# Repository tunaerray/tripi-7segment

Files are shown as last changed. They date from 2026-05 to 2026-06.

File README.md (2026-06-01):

# TRIPI 7-Segment Display Module

A peripheral expansion board designed for the TRIPI (Trion-based FPGA) platform, featuring 8 seven-segment displays, external push buttons, switches, and a reset mechanism.

## Overview

This project provides a ready-to-use hardware module for FPGA-based digital logic and display control applications. The board connects directly to the 40-pin GPIO header of the TRIPI FPGA board, enabling students and developers to implement and test digital systems without additional wiring or breadboarding.

## Features

- 8x seven-segment displays for multi-digit numeric output
- External push buttons and switches for user input
- Reset functionality for system control
- 2-layer PCB designed for the TRIPI FPGA 40-pin GPIO header
- Plug-and-play integration with the Trion-based FPGA platform

## Use Case

Designed as an educational hardware platform, this module allows students to:

- Implement digital logic circuits on a real FPGA
- Develop display control and multiplexing applications
- Prototype FPGA-based digital systems
- Learn hardware-software co-design in an embedded context

## Hardware

- **Platform:** TRIPI (Trion-based FPGA)
- **Interface:** 40-pin GPIO header
- **PCB:** 2-layer board
- **Display:** 8x seven-segment displays
- **Input:** Push buttons, DIP switches, reset button

## Images

### PCB Front

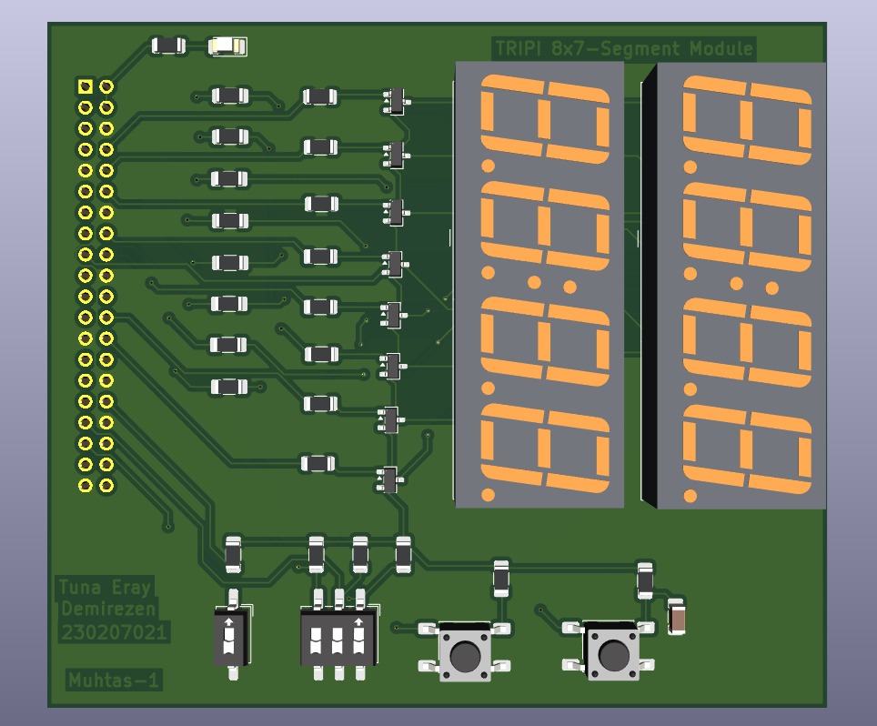
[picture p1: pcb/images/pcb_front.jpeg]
PCB Front


### PCB Back

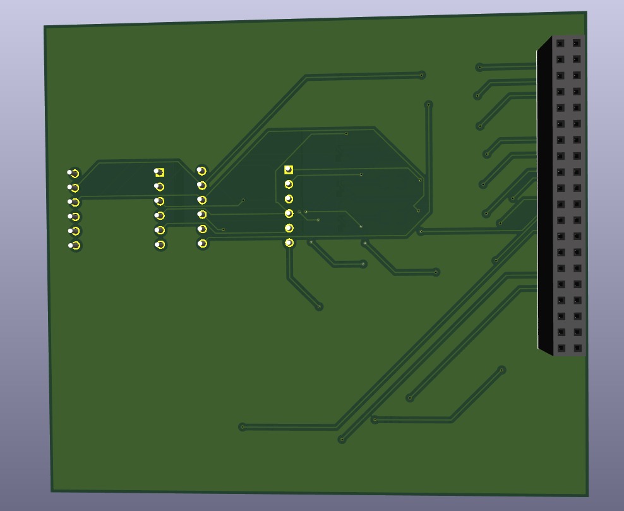
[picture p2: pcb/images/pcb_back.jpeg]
PCB Back

.

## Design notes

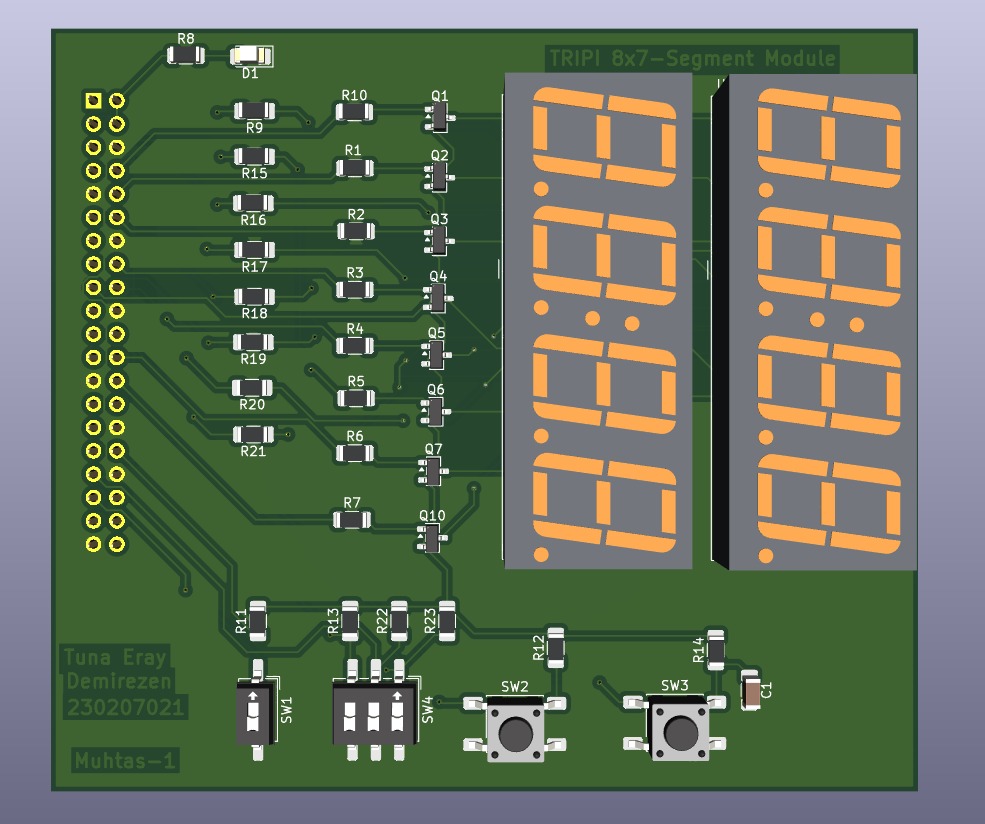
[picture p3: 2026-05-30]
pcb/images/tripi_7segment_pcb_front.jpeg

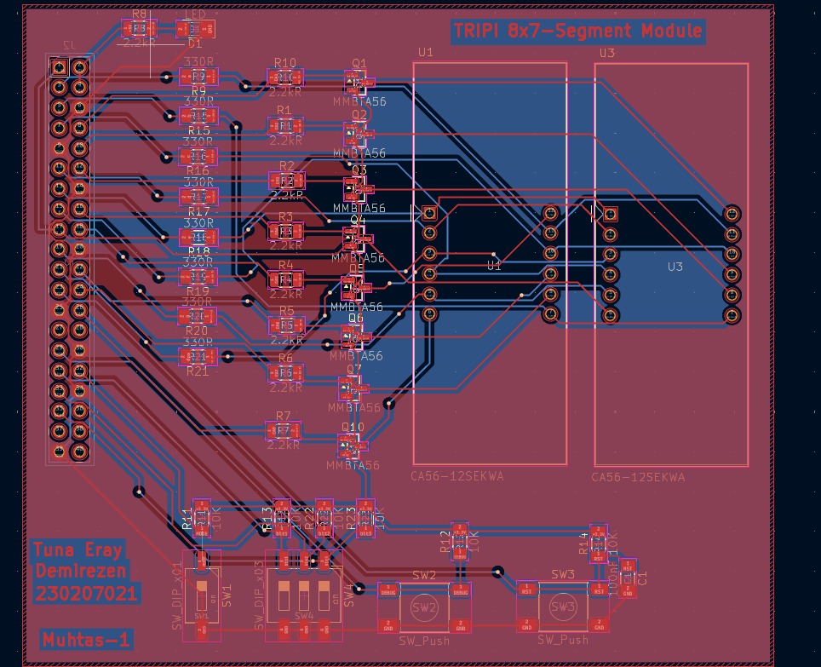
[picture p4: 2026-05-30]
pcb/images/pcb_layout.jpeg

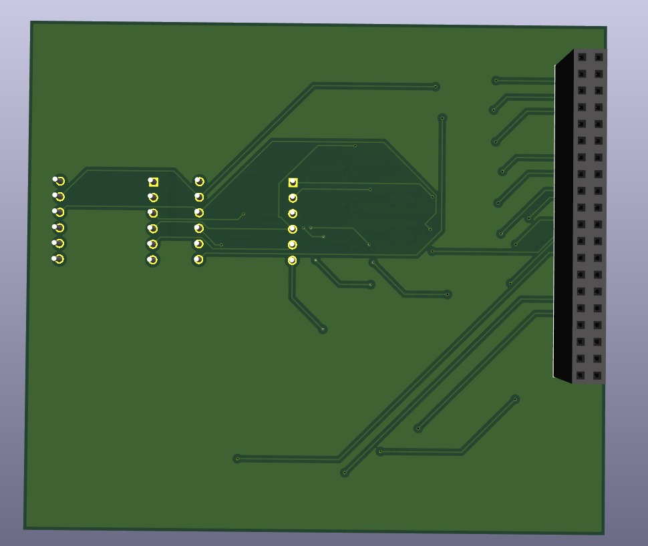
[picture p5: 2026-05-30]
pcb/images/tripi_7segment_pcb_back.jpeg

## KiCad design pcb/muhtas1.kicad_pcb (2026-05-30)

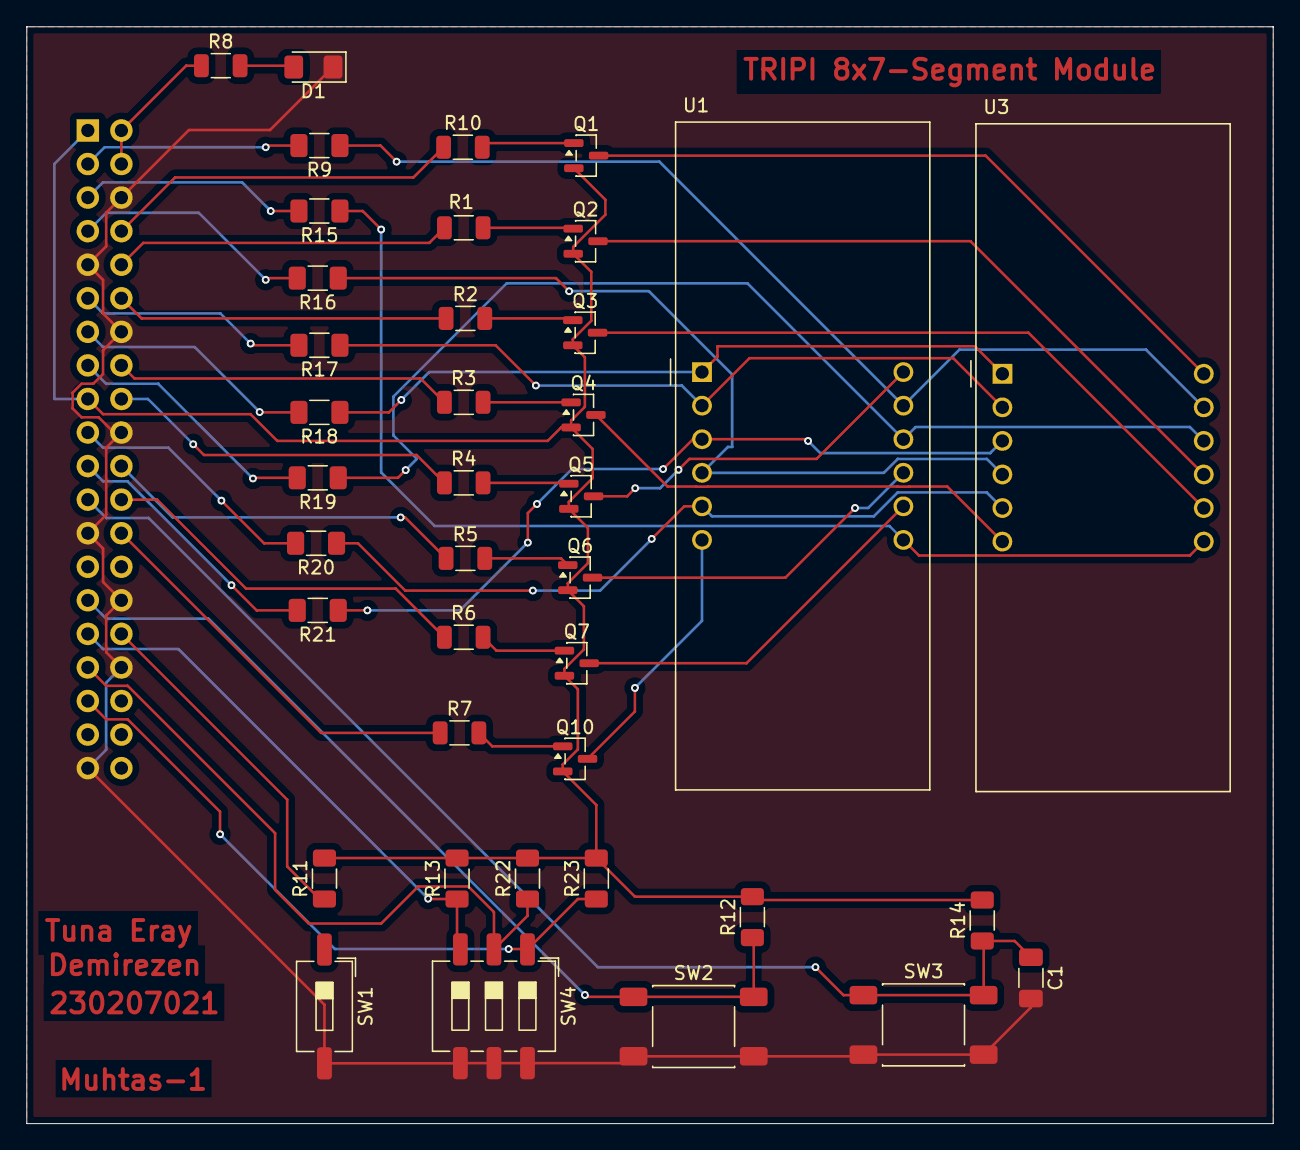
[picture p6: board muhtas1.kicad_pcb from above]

Board: 2 copper layers, 94.3 x 83.0 mm, 40 parts (1 on the bottom side), 50 nets.

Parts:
C1: 100nF; C_1206_3216Metric_Pad1.33x1.80mm_HandSolder
D1: LED; LED_1206_3216Metric_Pad1.42x1.75mm_HandSolder
J2: Conn_02x20_Odd_Even; PinSocket_2x20_P2.54mm_Vertical
Q1, Q2, Q3, Q4, Q5, Q6, Q7, Q10: MMBTA56; SOT-23
R1, R2, R3, R4, R5, R6, R7, R8, R10: 2.2kR; R_1206_3216Metric
R9, R15, R16, R17, R18, R19, R20, R21: 330R; R_1206_3216Metric_Pad1.30x1.75mm_HandSolder
R11, R12, R13, R14, R22, R23: 10K; R_1206_3216Metric_Pad1.30x1.75mm_HandSolder
SW1: SW_DIP_x01; SW_DIP_SPSTx01_Slide_6.7x4.1mm_W8.61mm_P2.54mm_LowProfile
SW2, SW3: SW_Push; SW_Push_1P1T_NO_E-Switch_TL3301NxxxxxG
SW4: SW_DIP_x03; SW_DIP_SPSTx03_Slide_6.7x9.18mm_W8.61mm_P2.54mm_LowProfile
U1, U3: CA56-12SEKWA

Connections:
+3.3V: J2.1, J2.17, Q1.2 (E), Q2.2 (E), Q3.2 (E), Q4.2 (E), Q5.2 (E), Q6.2 (E), Q7.2 (E), Q10.2 (E), R11.2, R12.2, R13.2, R14.2, R22.2, R23.2
+5V: J2.2, J2.4, R8.1
CA1: J2.8, R10.1
CA2: J2.10, R1.1
CA3: J2.12, R2.1
CA4: J2.16, R3.1
CA5: J2.18, R4.1
CA6: J2.22, R5.1
CA7: J2.24, R6.1
CA8: J2.26, R7.1
DEBUG: J2.29, R12.1, SW2.1
GND: C1.2, D1.1 (K), J2.6, J2.9, J2.14, J2.20, J2.25, J2.30, J2.34, J2.39, SW1.2, SW2.2, SW3.2, SW4.4, SW4.5, SW4.6
MODE: J2.32, R11.1, SW1.1
unnamed: D1.2 (A), R8.2
unnamed: Q1.1 (B), R10.2
unnamed: Q1.3 (C), U3.12 (CA1)
unnamed: Q2.1 (B), R1.2
unnamed: Q2.3 (C), U3.9 (CA2)
unnamed: Q3.1 (B), R2.2
unnamed: Q3.3 (C), U3.8 (CA3)
unnamed: Q4.1 (B), R3.2
unnamed: Q4.3 (C), U3.6 (CA4)
unnamed: Q5.1 (B), R4.2
unnamed: Q5.3 (C), U1.12 (CA1)
unnamed: Q6.1 (B), R5.2
unnamed: Q6.3 (C), U1.9 (CA2)
unnamed: Q7.1 (B), R6.2
unnamed: Q7.3 (C), U1.8 (CA3)
unnamed: Q10.1 (B), R7.2
unnamed: Q10.3 (C), U1.6 (CA4)
unnamed: R21.1, U1.3 (DPX), U3.3 (DPX)
unnamed: R9.1, U1.11 (a), U3.11 (a)
unnamed: R15.1, U1.7 (b), U3.7 (b)
unnamed: R16.1, U1.4 (c), U3.4 (c)
unnamed: R17.1, U1.2 (d), U3.2 (d)
unnamed: R18.1, U1.1 (e), U3.1 (e)
unnamed: R19.1, U1.10 (f), U3.10 (f)
unnamed: R20.1, U1.5 (g), U3.5 (g)
RST: C1.1, J2.23, R14.1, SW3.1
a: J2.3, R9.2
b: J2.5, R15.2
bit1: J2.31, R13.1, SW4.3
bit2: J2.33, R22.1, SW4.2
bit3: J2.35, R23.1, SW4.1
c: J2.7, R16.2
d: J2.11, R17.2
dpx: J2.21, R21.2
e: J2.13, R18.2
f: J2.15, R19.2
g: J2.19, R20.2
